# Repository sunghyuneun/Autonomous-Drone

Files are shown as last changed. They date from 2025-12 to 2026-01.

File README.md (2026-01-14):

# Overview
Similar to Turtlebot 3

- Features
    - Raspberry Pi 5
    - Arduino
    - DC Motors
    - Odometry
        - Encoders
        - IMU
        - LiDAR
    - SLAM (w/ LiDAR)
    - Obstacle Avoidance with PPO

# Progress

Drone Moving
https://www.youtube.com/watch?v=rg7pI7mpyLs

## LiDAR
Visualized LiDAR information from Raspberry Pi onto Desktop using RViz2.

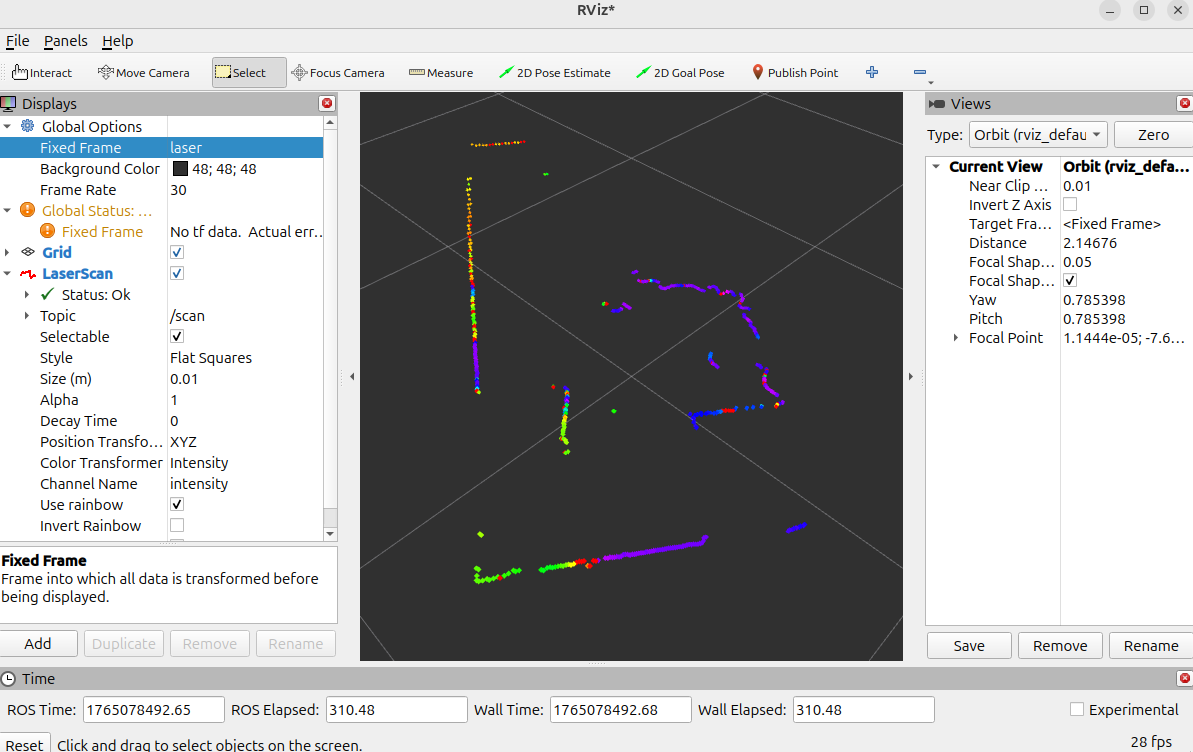
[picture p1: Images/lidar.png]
LiDar


After I moved, I could not set up proper port forwarding at my dorm between my Raspberry Pi and my VM, so I switched to Foxglove.

Here is an example Map with my robot and LiDAR visualized on it.
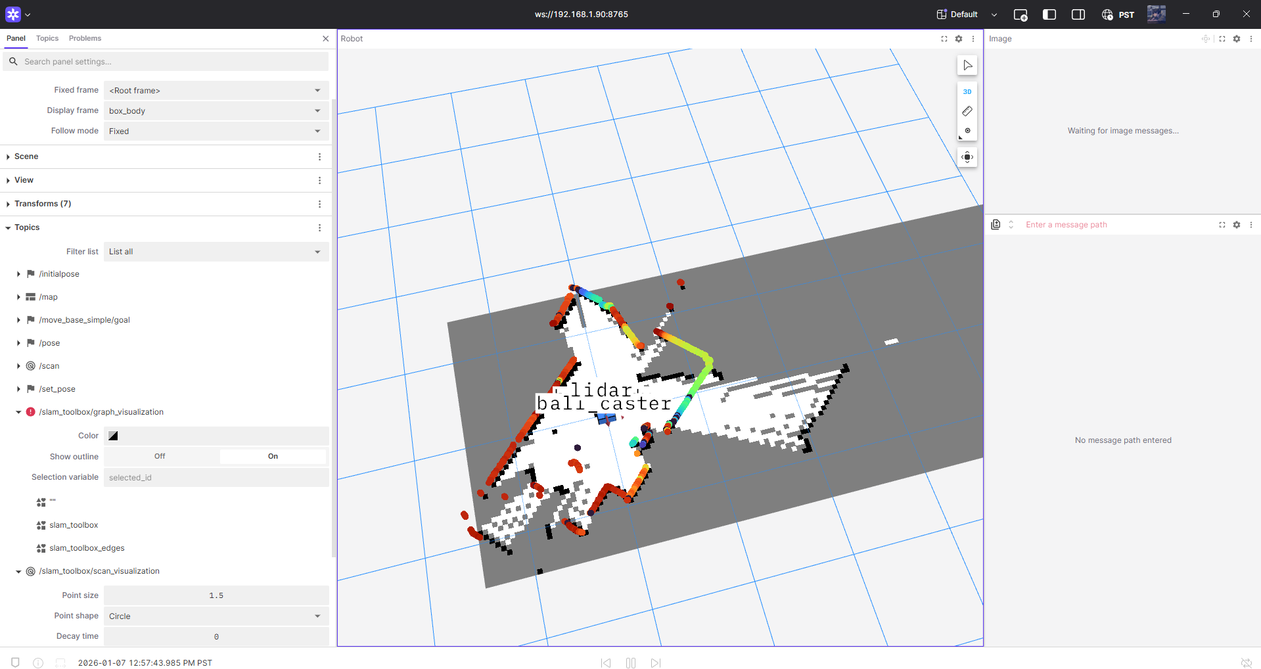
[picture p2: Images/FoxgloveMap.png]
Foxglove Map


## Assembly
Finished the CAD assembly, and built it in real life. 

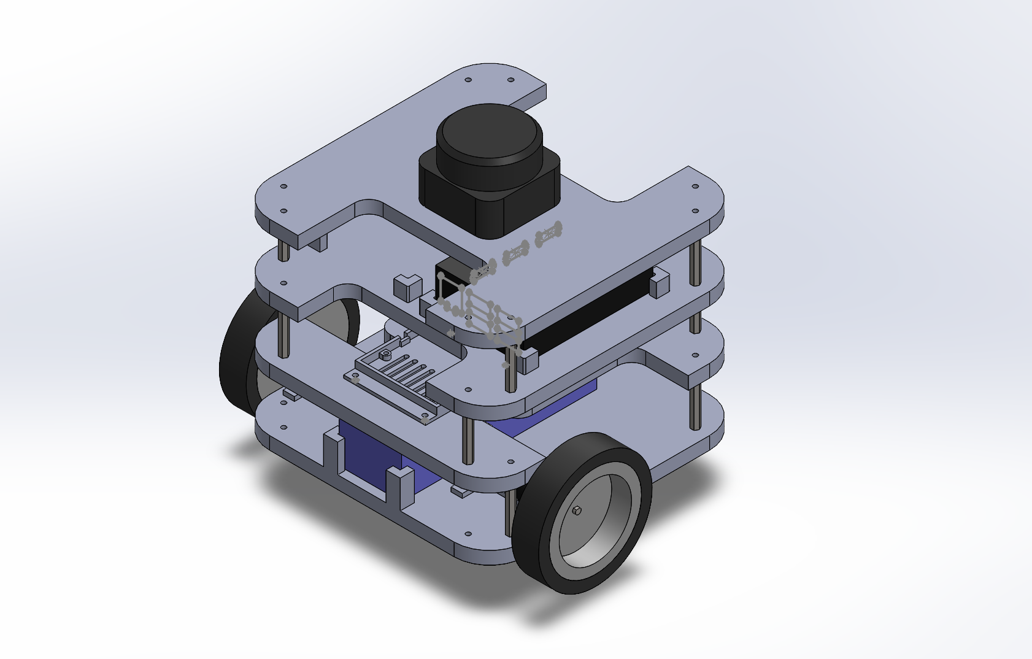
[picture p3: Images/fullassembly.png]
Full Assembly


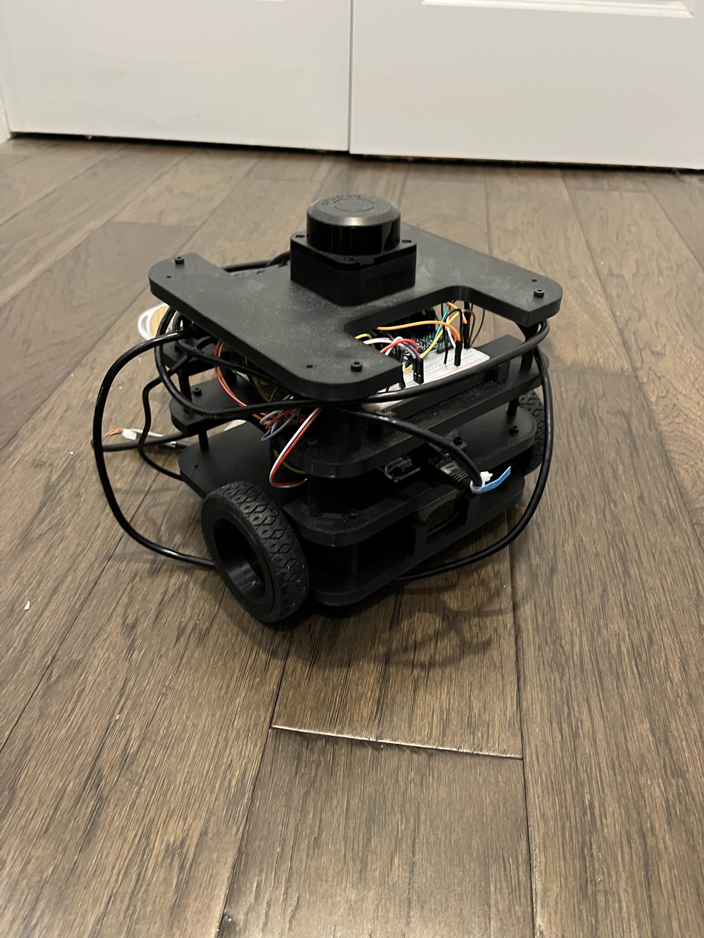
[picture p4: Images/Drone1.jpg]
Drone1


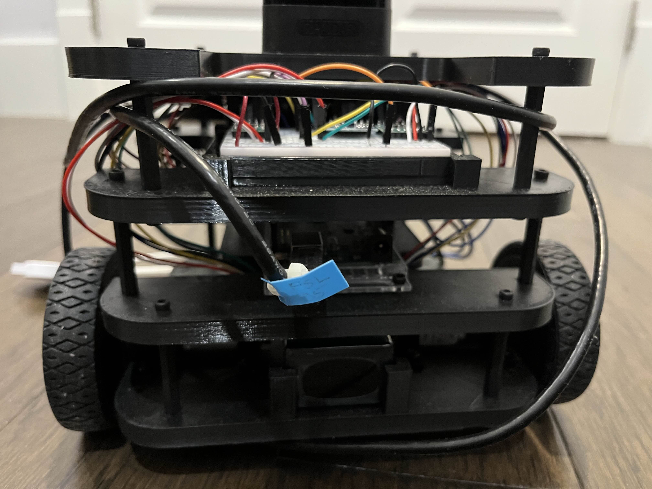
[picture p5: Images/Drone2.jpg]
Drone2


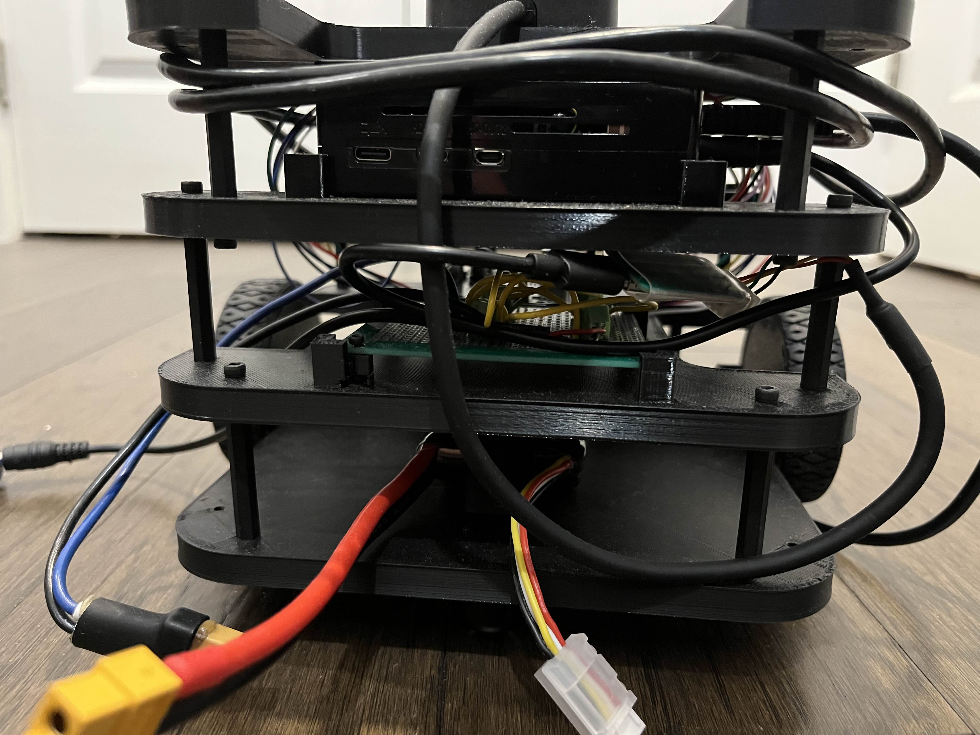
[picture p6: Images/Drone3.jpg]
Drone3


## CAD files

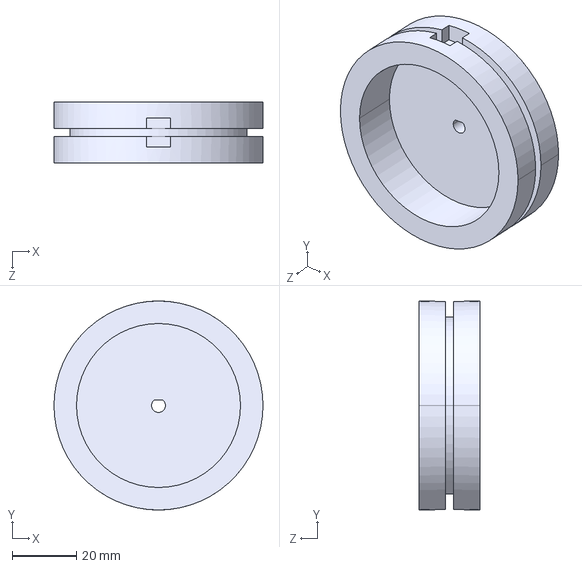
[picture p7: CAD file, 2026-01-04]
CAD/individual parts/wheel_rim.STEP
65.0 x 65.0 x 19.0 mm

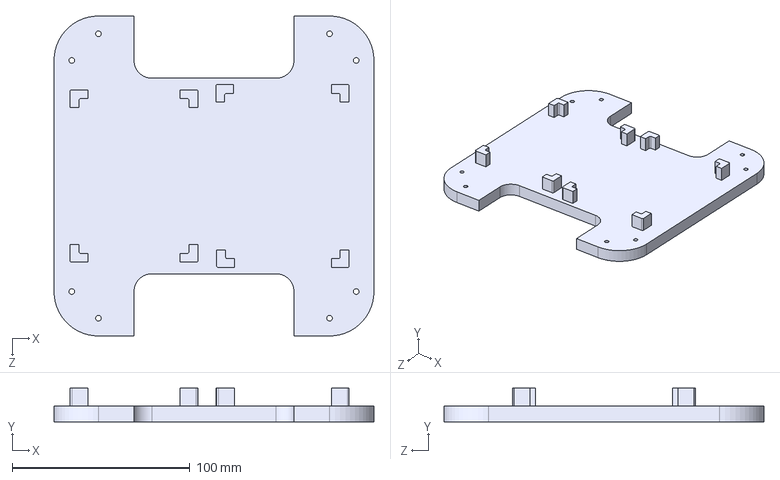
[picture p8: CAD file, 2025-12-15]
CAD/plates/plate3.STEP
180.0 x 19.0 x 180.0 mm

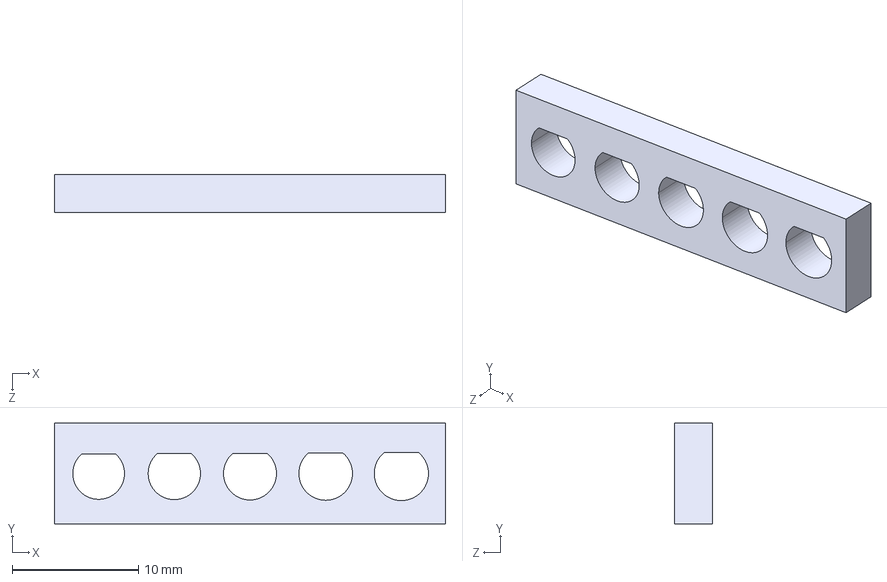
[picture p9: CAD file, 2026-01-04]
CAD/testprintagain.STEP
31.0 x 8.00 x 3.00 mm

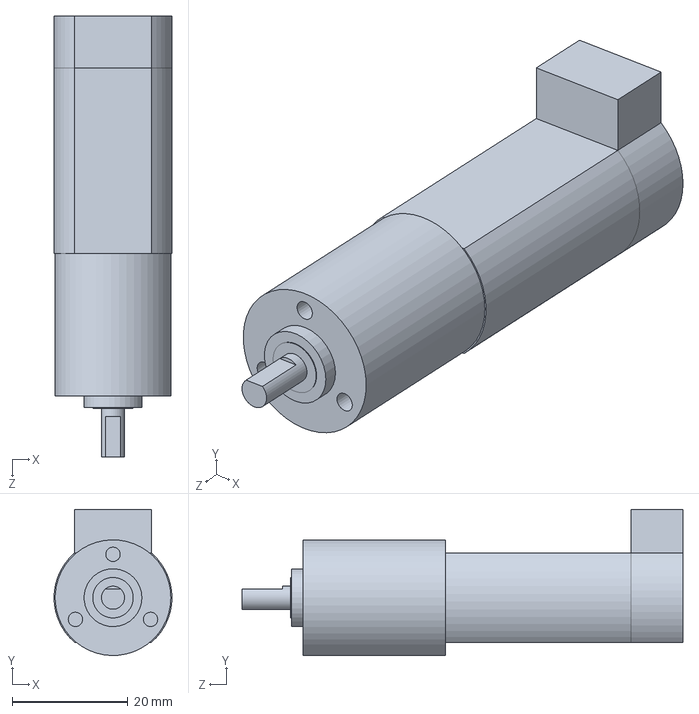
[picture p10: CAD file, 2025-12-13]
CAD/individual parts/motor.SLDPRT
20.4 x 25.2 x 76.2 mm

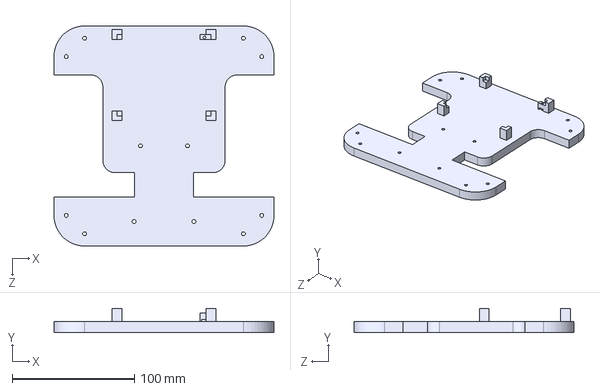
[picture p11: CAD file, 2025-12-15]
CAD/plates/plate2.STEP
180.0 x 20.0 x 180.0 mm

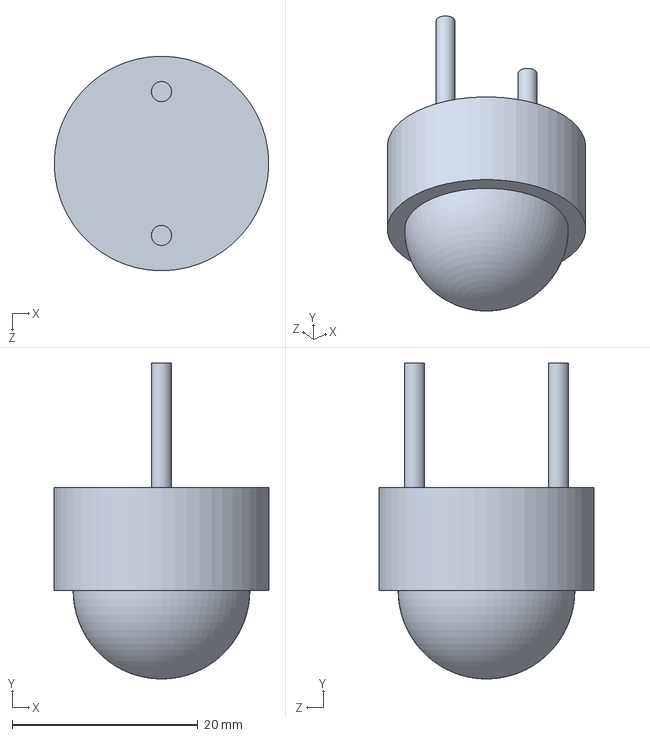
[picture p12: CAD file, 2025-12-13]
CAD/individual parts/ball_caster.SLDPRT
23.1 x 34.0 x 23.1 mm

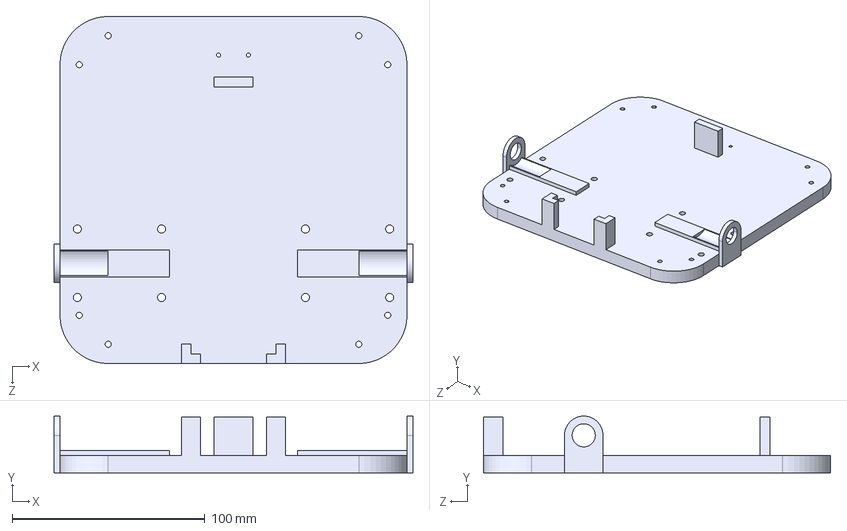
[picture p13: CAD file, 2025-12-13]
CAD/plates/plate1.STEP
186.0 x 29.5 x 180.0 mm

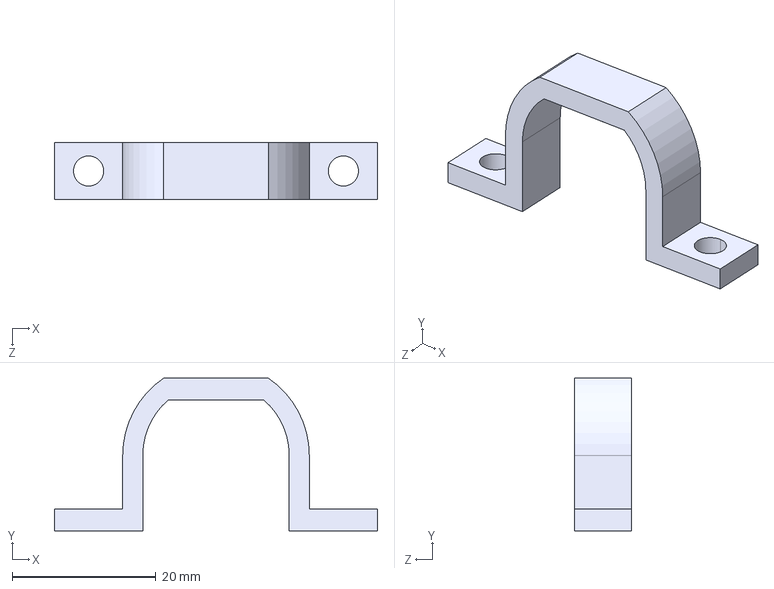
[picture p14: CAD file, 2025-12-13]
CAD/individual parts/clamp2.STEP
45.0 x 21.2 x 8.00 mm

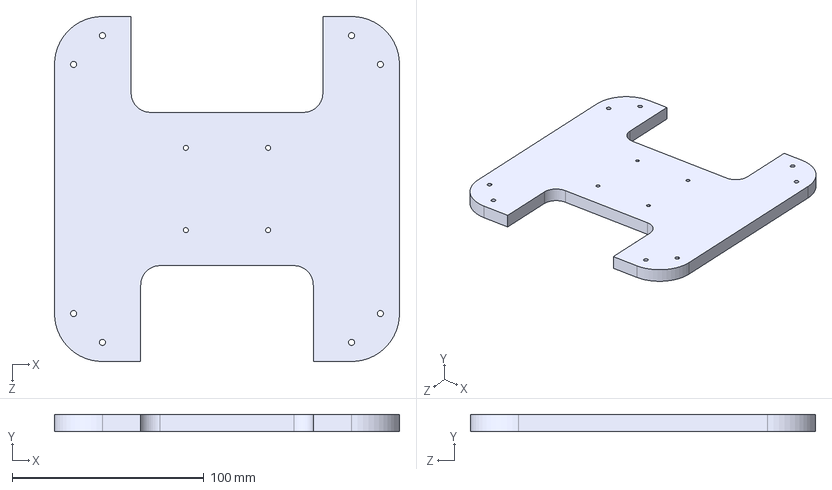
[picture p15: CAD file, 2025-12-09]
CAD/plates/plate4.STEP
180.0 x 9.00 x 180.0 mm

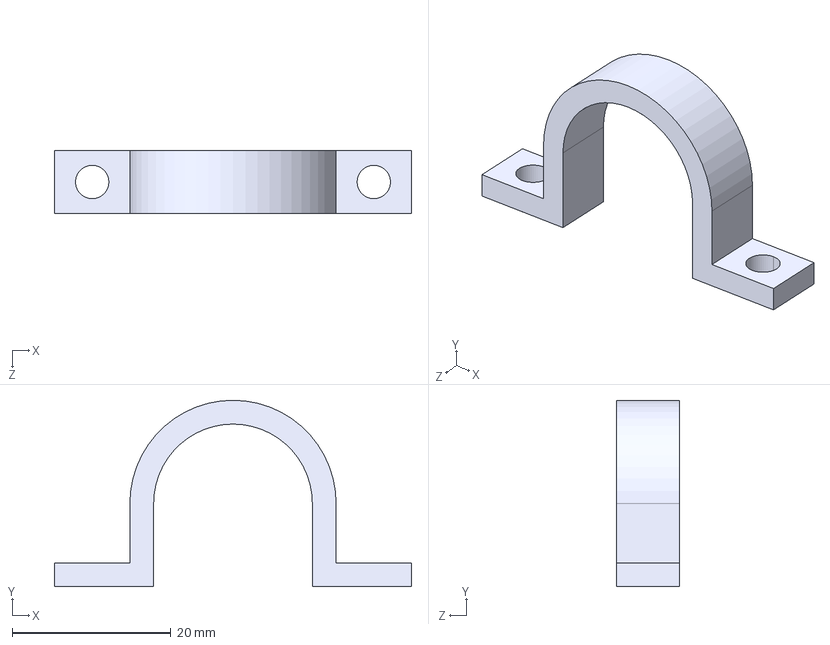
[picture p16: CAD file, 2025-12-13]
CAD/individual parts/clamp1.STEP
45.0 x 23.5 x 8.00 mm

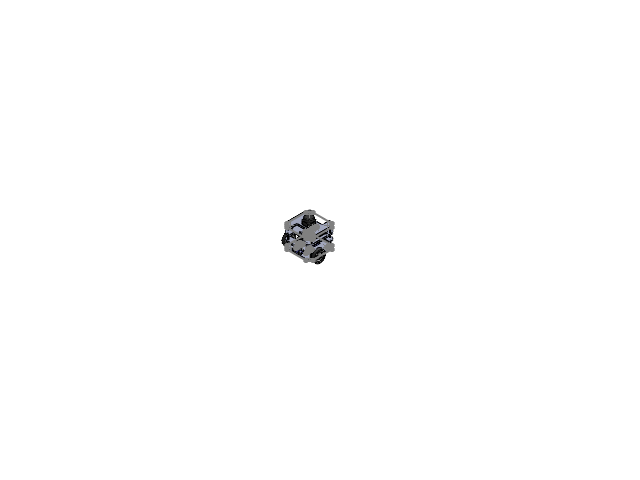
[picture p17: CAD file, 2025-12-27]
CAD/full_assembly.SLDASM
plate1
lipo
motor x 2
ball_caster
wheel_rim x 2
wheel_tire x 2
hex_standoff x 11
clamp1 x 2
clamp2 x 2
plate2
arduino_baseplate
plate3
raspberry_pi
plate4
lidar

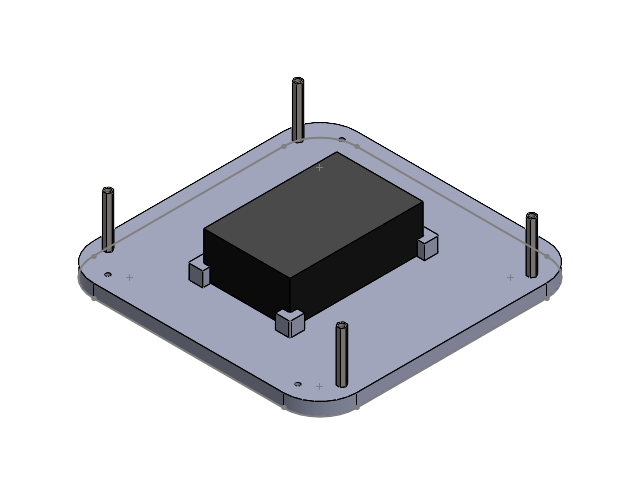
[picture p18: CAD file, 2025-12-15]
CAD/assembly3.SLDASM
plate3
raspberry_pi
hex_standoff x 4

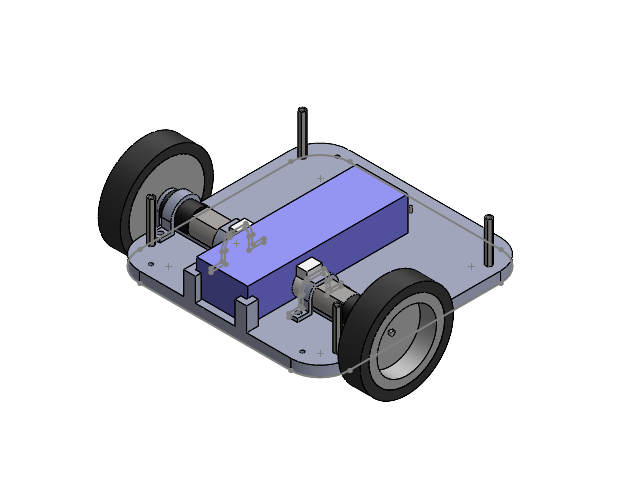
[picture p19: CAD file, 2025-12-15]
CAD/assembly1.SLDASM
plate1
lipo
motor x 2
ball_caster
wheel_rim x 2
wheel_tire x 2
hex_standoff x 4
clamp1 x 2
clamp2 x 2

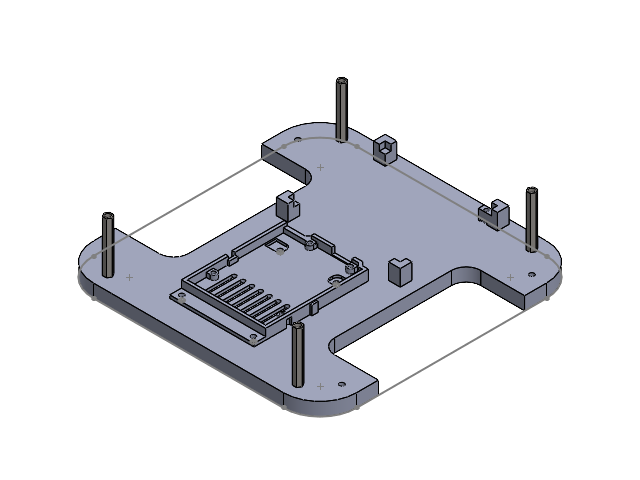
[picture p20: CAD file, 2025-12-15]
CAD/assembly2.SLDASM
plate2
arduino_baseplate
hex_standoff x 4

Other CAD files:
CAD/assembly4.SLDASM
CAD/full_assembly_stepper.SLDASM
CAD/assembly1_stepper.SLDASM
CAD/assembly2_stepper.SLDASM
CAD/individual parts/Arduino UNO Rev3_base original.stp
CAD/individual parts/GearMotor.SLDPRT
CAD/individual parts/Nema17.SLDPRT
CAD/individual parts/RPLidar C1.stp
CAD/individual parts/clamp1.SLDPRT
CAD/individual parts/clamp2.SLDPRT
CAD/individual parts/hex_standoff.SLDPRT
CAD/individual parts/lidar.SLDPRT
CAD/individual parts/lipo.SLDPRT
CAD/individual parts/raspberry_pi.SLDPRT
CAD/individual parts/wheel_rim.SLDPRT
CAD/individual parts/wheel_tire.SLDPRT
CAD/pcbtestprint.SLDPRT
CAD/pcbtestprint.STEP
CAD/plates/plate1.SLDPRT
CAD/plates/plate1_stepper.SLDPRT
CAD/plates/plate1_stepper.STEP
CAD/plates/plate2.SLDPRT
CAD/plates/plate2_stepper.SLDPRT
CAD/plates/plate2_stepper.STEP
CAD/plates/plate3.SLDPRT
CAD/plates/plate4.SLDPRT
CAD/testprint.SLDPRT
CAD/testprint.STEP
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

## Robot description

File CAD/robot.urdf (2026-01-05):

<robot name="autonomous_drone">
  <link name="box_body"> 
    <visual>
      <origin xyz="0 0 .0705" rpy="0 0 0" />
      <geometry>
        <box size=".18 .18 .141" />
      </geometry>
      <material name="Blue">
        <color rgba=".2588 .5294 .9608 .7"/>
      </material>
    </visual>
    
    <collision>
      <origin xyz="0 0 .0705" rpy="0 0 0"/>
      <geometry>
        <box size=".18 .18 .141" />
      </geometry>
    </collision>
  </link>

  <link name="wheel_right">
    <visual>
      <origin xyz="0 0 0" rpy="0 1.5708 0"/>
      <geometry>
        <cylinder radius = "0.04" length = ".019" />
      </geometry>
      <material name="Black">
        <color rgba="0 0 0 1"/>
      </material>
    </visual>
    
    <collision>
      <origin xyz="0 0 0" rpy="0 1.5708 0"/>
      <geometry>
        <cylinder radius = "0.04" length = ".019" />
      </geometry>
    </collision>
  </link>

  <link name="wheel_left" >
    <visual>
      <origin xyz="0 0 0" rpy="0 -1.5708 0"/>
      <geometry>
        <cylinder radius = "0.04" length = ".019" />
      </geometry>
      <material name="Black">
        <color rgba="0 0 0 1"/>
      </material>
    </visual>
    
    <collision>
      <origin xyz="0 0 0" rpy="0 -1.5708 0"/>
      <geometry>
        <cylinder radius = "0.04" length = ".019" />
      </geometry>
    </collision>
  </link>

  <link name="imu" >
    <visual>
      <origin xyz="0 0 0" rpy="0 0 0" />
      <geometry>
        <box size="0.021 .016 .005" />
      </geometry>
      <material name="Green">
        <color rgba="0 .3686 .0196 1"/>
      </material>
    </visual>
    
    <collision>
      <origin xyz="0 0 0" rpy="0 0 0" />
      <geometry>
        <box size="0.021 .016 .005" />
      </geometry>
    </collision>
  </link>

  <link name="lidar" >
    <visual>
      <origin xyz="0 0 0" rpy="0 0 0" />
      <geometry>
        <box size="0.0556 .0556 .0413" />
      </geometry>
      <material name="Black">
        <color rgba="0 0 0 1"/>
      </material>
    </visual>
    
    <collision>
      <origin xyz="0 0 0" rpy="0 0 0" />
      <geometry>
        <box size="0.0556 .0556 .0413" />
      </geometry>
    </collision>
  </link>

  <link name="ball_caster" >
    <visual>
      <origin xyz="0 0 0" rpy="0 0 0" />
      <geometry>
        <sphere radius =".009525" />
      </geometry>
      <material name="Blue">
        <color rgba=".2588 .5294 .9608 1"/>
      </material>
    </visual>
    
    <collision>
      <origin xyz="0 0 0" rpy="0 0 0" />
      <geometry>
        <sphere radius =".009525" />
      </geometry>
    </collision>
  </link>

  <joint name="right_wheel_joint" type="continuous">
    <origin xyz = "0.103 0.038 0.0195"/>
    <axis xyz="1 0 0" />
    <parent link="box_body"/>
    <child link="wheel_right"/>
  </joint>

  <joint name="left_wheel_joint" type="continuous">
    <origin xyz="-0.103 0.038 0.0195"/>
    <axis xyz="1 0 0" />
    <parent link="box_body"/>
    <child link="wheel_left"/>
  </joint>

  <joint name="imu_joint" type="fixed">
    <origin xyz="-0.0174 0.05225 0.114"/>
    <parent link="box_body"/>
    <child link="imu"/>
  </joint>

  <joint name="lidar_joint" type="fixed">
    <origin xyz="0 0 .16165" rpy="0 0 -1.5708"/>
    <parent link="box_body"/>
    <child link="lidar"/>
  </joint>

  <joint name="ball_joint" type="fixed">
    <origin xyz="0 -.07 -.01113"/>
    <parent link="box_body"/>
    <child link="ball_caster"/>
  </joint>
</robot>

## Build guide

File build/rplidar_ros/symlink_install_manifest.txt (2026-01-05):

/home/hyun/Autonomous-Drone/install/rplidar_ros/share/rplidar_ros/launch/rplidar_a1_launch.py
/home/hyun/Autonomous-Drone/install/rplidar_ros/share/rplidar_ros/launch/rplidar_a2m12_launch.py
/home/hyun/Autonomous-Drone/install/rplidar_ros/share/rplidar_ros/launch/rplidar_a2m7_launch.py
/home/hyun/Autonomous-Drone/install/rplidar_ros/share/rplidar_ros/launch/rplidar_a2m8_launch.py
/home/hyun/Autonomous-Drone/install/rplidar_ros/share/rplidar_ros/launch/rplidar_a3_launch.py
/home/hyun/Autonomous-Drone/install/rplidar_ros/share/rplidar_ros/launch/rplidar_c1_launch.py
/home/hyun/Autonomous-Drone/install/rplidar_ros/share/rplidar_ros/launch/rplidar_s1_launch.py
/home/hyun/Autonomous-Drone/install/rplidar_ros/share/rplidar_ros/launch/rplidar_s1_tcp_launch.py
/home/hyun/Autonomous-Drone/install/rplidar_ros/share/rplidar_ros/launch/rplidar_s2_launch.py
/home/hyun/Autonomous-Drone/install/rplidar_ros/share/rplidar_ros/launch/rplidar_s2e_launch.py
/home/hyun/Autonomous-Drone/install/rplidar_ros/share/rplidar_ros/launch/rplidar_s3_launch.py
/home/hyun/Autonomous-Drone/install/rplidar_ros/share/rplidar_ros/launch/rplidar_t1_launch.py
/home/hyun/Autonomous-Drone/install/rplidar_ros/share/rplidar_ros/launch/view_rplidar_a1_launch.py
/home/hyun/Autonomous-Drone/install/rplidar_ros/share/rplidar_ros/launch/view_rplidar_a2m12_launch.py
/home/hyun/Autonomous-Drone/install/rplidar_ros/share/rplidar_ros/launch/view_rplidar_a2m7_launch.py
/home/hyun/Autonomous-Drone/install/rplidar_ros/share/rplidar_ros/launch/view_rplidar_a2m8_launch.py
/home/hyun/Autonomous-Drone/install/rplidar_ros/share/rplidar_ros/launch/view_rplidar_a3_launch.py
/home/hyun/Autonomous-Drone/install/rplidar_ros/share/rplidar_ros/launch/view_rplidar_c1_launch.py
/home/hyun/Autonomous-Drone/install/rplidar_ros/share/rplidar_ros/launch/view_rplidar_s1_launch.py
/home/hyun/Autonomous-Drone/install/rplidar_ros/share/rplidar_ros/launch/view_rplidar_s1_tcp_launch.py
/home/hyun/Autonomous-Drone/install/rplidar_ros/share/rplidar_ros/launch/view_rplidar_s2_launch.py
/home/hyun/Autonomous-Drone/install/rplidar_ros/share/rplidar_ros/launch/view_rplidar_s2e_launch.py
/home/hyun/Autonomous-Drone/install/rplidar_ros/share/rplidar_ros/launch/view_rplidar_s3_launch.py
/home/hyun/Autonomous-Drone/install/rplidar_ros/share/rplidar_ros/launch/view_rplidar_t1_launch.py
/home/hyun/Autonomous-Drone/install/rplidar_ros/share/rplidar_ros/rviz/rplidar_ros.rviz
/home/hyun/Autonomous-Drone/install/rplidar_ros/lib/rplidar_ros/rplidar_node
/home/hyun/Autonomous-Drone/install/rplidar_ros/lib/rplidar_ros/rplidar_composition
/home/hyun/Autonomous-Drone/install/rplidar_ros/lib/rplidar_ros/rplidar_client
/home/hyun/Autonomous-Drone/install/rplidar_ros/share/ament_index/resource_index/package_run_dependencies/rplidar_ros
/home/hyun/Autonomous-Drone/install/rplidar_ros/share/ament_index/resource_index/parent_prefix_path/rplidar_ros
/home/hyun/Autonomous-Drone/install/rplidar_ros/share/rplidar_ros/environment/ament_prefix_path.sh
/home/hyun/Autonomous-Drone/install/rplidar_ros/share/rplidar_ros/environment/ament_prefix_path.dsv
/home/hyun/Autonomous-Drone/install/rplidar_ros/share/rplidar_ros/environment/path.sh
/home/hyun/Autonomous-Drone/install/rplidar_ros/share/rplidar_ros/environment/path.dsv
/home/hyun/Autonomous-Drone/install/rplidar_ros/share/rplidar_ros/local_setup.bash
/home/hyun/Autonomous-Drone/install/rplidar_ros/share/rplidar_ros/local_setup.sh
/home/hyun/Autonomous-Drone/install/rplidar_ros/share/rplidar_ros/local_setup.zsh
/home/hyun/Autonomous-Drone/install/rplidar_ros/share/rplidar_ros/local_setup.dsv
/home/hyun/Autonomous-Drone/install/rplidar_ros/share/rplidar_ros/package.dsv
/home/hyun/Autonomous-Drone/install/rplidar_ros/share/ament_index/resource_index/packages/rplidar_ros
/home/hyun/Autonomous-Drone/install/rplidar_ros/share/rplidar_ros/cmake/ament_cmake_export_dependencies-extras.cmake
/home/hyun/Autonomous-Drone/install/rplidar_ros/share/rplidar_ros/cmake/ament_cmake_export_include_directories-extras.cmake
/home/hyun/Autonomous-Drone/install/rplidar_ros/share/rplidar_ros/cmake/rplidar_rosConfig.cmake
/home/hyun/Autonomous-Drone/install/rplidar_ros/share/rplidar_ros/cmake/rplidar_rosConfig-version.cmake
/home/hyun/Autonomous-Drone/install/rplidar_ros/share/rplidar_ros/package.xml

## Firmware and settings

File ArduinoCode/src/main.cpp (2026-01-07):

#define ENCODER_OPTIMIZE_INTERRUPTS

#include <Arduino.h>
#include <Wire.h>
#include <Adafruit_Sensor.h>
#include <Adafruit_MPU6050.h>
#include <Encoder.h>

/*
IMU SCL - SCL
IMU SDA - SDA

1 - Right Motor
2 - Left Motor

EN 1 - Pin 9
EN 2 - Pin 10
PH 1 - Pin 11
PH 2 - Pin 12

Hall Signal 1 A - Pin 2
Hall Signal 2 A - Pin 3
Hall Signal 1 B - Pin 4
Hall Signal 2 B - Pin 5
*/

const int HALL1A = 2;
const int HALL2A = 3;
const int HALL1B = 4;
const int HALL2B = 5;

const int EN1 = 9;
const int EN2 = 10;
const int PH1 = 11;
const int PH2 = 12;

const float PPR = 11.0;
const float GEAR_RATIO = 157.0;
const float WHEEL_RADIUS = 0.04;
const float TICKS_PER_REV = PPR * GEAR_RATIO;
const float METERS_PER_TICK = (WHEEL_RADIUS * 2 * PI) / TICKS_PER_REV;

unsigned int last_time = 0;
long last_pos1 = 0;
long last_pos2 = 0;
long current_pos1 = 0;
long current_pos2 = 0;

const int interval = 50;

float X_ACCEL_BIAS;
float Y_ACCEL_BIAS;
float Z_ACCEL_BIAS;
float X_GYRO_BIAS;
float Y_GYRO_BIAS;
float Z_GYRO_BIAS;

Adafruit_MPU6050 mpu;
Encoder encoder1(HALL1A,HALL1B);
Encoder encoder2(HALL2A,HALL2B);

float vel_1 = 0.0;
float vel_2 = 0.0;


//float kp = 150.0;
//float ki = 40.0;
//float kd = 1.0;
float kp = 250.0;
float ki = 100.0;
float kd = 0.0;
//Yeah these seem to work let's just go with a PI controller lol

float target_vel_1 = 0.0;
float target_vel_2 = 0.0;
float integral1 = 0.0;
float integral2 = 0.0;
float last_error_1 = 0.0;
float last_error_2 = 0.0;


void IMU_Calibration();
void print_IMU();
void drive_motor(float, float);

void setup() {
  pinMode(HALL1A, INPUT);
  pinMode(HALL2A, INPUT);
  pinMode(HALL1B, INPUT);
  pinMode(HALL2B, INPUT);

  pinMode(EN1, OUTPUT);
  pinMode(EN2, OUTPUT);
  pinMode(PH1, OUTPUT);
  pinMode(PH2, OUTPUT);

  Serial.begin(115200);
  while (!Serial){
    delay(10);
  }

  if (!mpu.begin()){
    Serial.println("Failed to find MPU6050!");
    while (1){
      delay(10);
    }
  }

  encoder1.write(0);
  encoder2.write(0);

  mpu.setAccelerometerRange(MPU6050_RANGE_16_G);
  mpu.setGyroRange(MPU6050_RANGE_250_DEG);
  mpu.setFilterBandwidth(MPU6050_BAND_21_HZ);
  Serial.println("");
  delay(100);
  IMU_Calibration();
}

void loop() {
  unsigned long current_time = millis();

  sensors_event_t a, g, temp;
  mpu.getEvent(&a, &g, &temp);

  if (Serial.available() > 0){
    char key = Serial.read();
    if (key == 'R'){
      target_vel_1 = -1 * Serial.parseFloat();
      Serial.print("R: ");
      Serial.println(target_vel_1);
    }
    else if (key == 'L'){
      target_vel_2 = Serial.parseFloat();
      Serial.print("L: ");
      Serial.println(target_vel_2);
    }
  }

  if ((current_time - last_time) >= interval){
    current_pos1 = encoder1.read();
    current_pos2 = encoder2.read();

    float time_delta = (current_time - last_time) / 1000.0;
    vel_1 = (current_pos1 - last_pos1) * METERS_PER_TICK / time_delta;
    vel_2 = (current_pos2 - last_pos2) * METERS_PER_TICK / time_delta;
    Serial.print("V:");
    Serial.print(-1 * vel_1);
    Serial.print(",");
    Serial.print(vel_2);
    Serial.print(",");

    last_pos1 = current_pos1;
    last_pos2 = current_pos2;
    last_time = current_time;

    Serial.print(a.acceleration.x - X_ACCEL_BIAS);
    Serial.print(",");
    Serial.print(a.acceleration.y - Y_ACCEL_BIAS);
    Serial.print(",");
    Serial.print(a.acceleration.z - Z_ACCEL_BIAS);
    Serial.print(",");

    Serial.print(g.gyro.x - X_GYRO_BIAS);
    Serial.print(",");
    Serial.print(g.gyro.y - Y_GYRO_BIAS);
    Serial.print(",");
    Serial.print(g.gyro.z - Z_GYRO_BIAS);
    Serial.print("\n");

    float error1 = target_vel_1 - vel_1;
    float error2 = target_vel_2 - vel_2;
    integral1 += error1 * time_delta;
    integral1 = constrain(integral1, -100, 100);
    integral2 += error2 * time_delta;
    integral2 = constrain(integral2, -100, 100);
    float derivative1 = (error1 - last_error_1) / time_delta;
    float derivative2 = (error2 - last_error_2) / time_delta;
    float output1 = (kp * error1) + (ki * integral1) + (kd * derivative1);
    float output2 = (kp * error2) + (ki * integral2) + (kd * derivative2);

    drive_motor(output1, output2);
    last_error_1 = error1;
    last_error_2 = error2;
  }
}

void IMU_Calibration(){

  const int CALIB_TIMESTEPS = 1000;
  double X_ACCEL_SUM = 0;
  double Y_ACCEL_SUM = 0;
  double Z_ACCEL_SUM = 0;
  double X_GYRO_SUM = 0;
  double Y_GYRO_SUM = 0;
  double Z_GYRO_SUM = 0;
  for (int i = 0; i < CALIB_TIMESTEPS; i++){
    sensors_event_t a, g, temp;
    mpu.getEvent(&a, &g, &temp);
    X_ACCEL_SUM += a.acceleration.x;
    Y_ACCEL_SUM += a.acceleration.y;
    Z_ACCEL_SUM += a.acceleration.z;

    X_GYRO_SUM += g.gyro.x;
    Y_GYRO_SUM += g.gyro.y;
    Z_GYRO_SUM += g.gyro.z;
  }

  X_ACCEL_BIAS = X_ACCEL_SUM / (float) CALIB_TIMESTEPS;
  Y_ACCEL_BIAS = Y_ACCEL_SUM / (float) CALIB_TIMESTEPS;
  Z_ACCEL_BIAS = Z_ACCEL_SUM / (float) CALIB_TIMESTEPS;
  X_GYRO_BIAS = X_GYRO_SUM / (float) CALIB_TIMESTEPS;
  Y_GYRO_BIAS = Y_GYRO_SUM / (float) CALIB_TIMESTEPS;
  Z_GYRO_BIAS = Z_GYRO_SUM / (float) CALIB_TIMESTEPS;
  /*
  Serial.print("IMU Calibrated.");

  Serial.print(X_ACCEL_BIAS);
  Serial.print(",");
  Serial.print(Y_ACCEL_BIAS);
  Serial.print(",");
  Serial.print(Z_ACCEL_BIAS);
  Serial.print(",");
  Serial.print(X_GYRO_BIAS);
  Serial.print(",");
  Serial.print(Y_GYRO_BIAS);
  Serial.print(",");
  Serial.print(Z_GYRO_BIAS);
  Serial.print("\n");
  */
}


void drive_motor(float power1, float power2){
  if (power1 >= 0) digitalWrite(PH1, HIGH);
  else digitalWrite(PH1, LOW);
  if (power2 >= 0) digitalWrite(PH2, HIGH);
  else digitalWrite(PH2, LOW);
  int pwmVal1;
  int pwmVal2;
  if (abs(target_vel_1) < 0.0001) pwmVal1 = 0;
  else pwmVal1 = constrain(abs(power1), 0, 255);
  if (abs(target_vel_2) < 0.0001) pwmVal2 = 0;
  else pwmVal2 = constrain(abs(power2), 0, 255);
  //Max is like 1.64 lol
  analogWrite(EN1, pwmVal1);
  analogWrite(EN2, pwmVal2);
}

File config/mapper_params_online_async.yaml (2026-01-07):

slam_toolbox:
  ros__parameters:

    # Plugin params
    solver_plugin: solver_plugins::CeresSolver
    ceres_linear_solver: SPARSE_NORMAL_CHOLESKY
    ceres_preconditioner: SCHUR_JACOBI
    ceres_trust_strategy: LEVENBERG_MARQUARDT
    ceres_dogleg_type: TRADITIONAL_DOGLEG
    ceres_loss_function: None

    # ROS Parameters
    odom_frame: odom
    map_frame: map
    base_frame: box_body
    scan_topic: /scan
    use_map_saver: true
    mode: mapping #localization

    # if you'd like to immediately start continuing a map at a given pose
    # or at the dock, but they are mutually exclusive, if pose is given
    # will use pose
    #map_file_name: test_steve
    # map_start_pose: [0.0, 0.0, 0.0]
    #map_start_at_dock: true

    debug_logging: false
    throttle_scans: 1
    transform_publish_period: 0.02 #if 0 never publishes odometry
    map_update_interval: 5.0
    resolution: 0.05
    max_laser_range: 20.0 #for rastering images
    minimum_time_interval: 0.5
    transform_timeout: 0.2
    tf_buffer_duration: 30.0
    stack_size_to_use: 40000000 #// program needs a larger stack size to serialize large maps
    enable_interactive_mode: true

    # General Parameters
    use_scan_matching: true
    use_scan_barycenter: true
    minimum_travel_distance: 0.5
    minimum_travel_heading: 0.5
    scan_buffer_size: 10
    scan_buffer_maximum_scan_distance: 10.0
    link_match_minimum_response_fine: 0.1  
    link_scan_maximum_distance: 1.5
    loop_search_maximum_distance: 3.0
    do_loop_closing: true 
    loop_match_minimum_chain_size: 10           
    loop_match_maximum_variance_coarse: 3.0  
    loop_match_minimum_response_coarse: 0.35    
    loop_match_minimum_response_fine: 0.45

    # Correlation Parameters - Correlation Parameters
    correlation_search_space_dimension: 0.5
    correlation_search_space_resolution: 0.01
    correlation_search_space_smear_deviation: 0.1 

    # Correlation Parameters - Loop Closure Parameters
    loop_search_space_dimension: 8.0
    loop_search_space_resolution: 0.05
    loop_search_space_smear_deviation: 0.03

    # Scan Matcher Parameters
    distance_variance_penalty: 0.5      
    angle_variance_penalty: 1.0    

    fine_search_angle_offset: 0.00349     
    coarse_search_angle_offset: 0.349   
    coarse_angle_resolution: 0.0349        
    minimum_angle_penalty: 0.9
    minimum_distance_penalty: 0.5
    use_response_expansion: true
    min_pass_through: 2
    occupancy_threshold: 0.1

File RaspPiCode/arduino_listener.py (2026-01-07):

import serial
import rclpy
from rclpy.node import Node
from nav_msgs.msg import Odometry
from sensor_msgs.msg import Imu
from geometry_msgs.msg import Quaternion, TransformStamped
import math
import tf_transformations

SERIAL_PORT = '/dev/ttyACM0'
BAUD_RATE = 115200
WHEEL_SEPARATION = .206 #206 mm

class ArduinoPublisher(Node):
    def __init__(self):
        super().__init__('arduino_publisher')

        self.imu_publisher = self.create_publisher(Imu, 'imu/raw_data', 10)
        self.get_logger().info("Created IMU Data Publisher")

        self.odom_publisher = self.create_publisher(Odometry, 'odom', 10)
        self.get_logger().info("Created Odometry Publisher")

        try:
            self.ser = serial.Serial(SERIAL_PORT, BAUD_RATE, timeout = .1)
            self.get_logger().info("Connected to Arduino Serial")
        except Exception as e:
            self.get_logger().error(f"Could not open serial port: {e}")

        self.x = 0.0
        self.y = 0.0
        self.th = 0.0
        self.last_time = self.get_clock().now()

        self.create_timer(0.02,self.publish_info)


    def publish_info(self):
        #write_data = "L0.1R0.1" + '\n'
        #self.ser.write(write_data.encode("utf-8"))
        if hasattr(self,'ser') and self.ser.in_waiting > 0:
            try:
                line = self.ser.readline().decode('utf-8', errors='ignore').strip()
                
                if line.startswith("V:"):
                    try:
                        data_parts = [float(val) for val in line[2:].split(',')]
                        
                        if len(data_parts) != 8:
                            self.get_logger().warn(f"Data packet length mismatch, length = {data_parts}")
                            return

                        
                        current_time = self.get_clock().now()

                        v_right, v_left = data_parts[0],data_parts[1]

                        #IMU stuff. 
                        imu_msg = Imu()
                        imu_msg.header.stamp = current_time.to_msg()
                        imu_msg.header.frame_id = "imu"

                        imu_msg.linear_acceleration.x = data_parts[2]
                        imu_msg.linear_acceleration.y = data_parts[3]
                        imu_msg.linear_acceleration.z = data_parts[4]
                        
                        imu_msg.angular_velocity.x = data_parts[5]
                        imu_msg.angular_velocity.x = data_parts[6]
                        imu_msg.angular_velocity.x = data_parts[7]

                        self.imu_publisher.publish(imu_msg)

                        #Odom stuff
                        dt = (current_time - self.last_time).nanoseconds / 1e9

                        v_linear = (v_right + v_left) / 2.0
                        v_angular = (v_right - v_left) / WHEEL_SEPARATION

                        self.x += (v_linear * math.cos(self.th)) * dt
                        self.y += (v_linear * math.sin(self.th)) * dt
                        self.th += v_angular * dt

                        q = tf_transformations.quaternion_from_euler(0, 0, self.th)
                        odom_msg = Odometry()
                        odom_msg.header.stamp = current_time.to_msg()
                        odom_msg.header.frame_id = "odom"
                        odom_msg.child_frame_id = 'box_body'

                        odom_msg.pose.pose.position.x = self.x
                        odom_msg.pose.pose.position.y = self.y
                        odom_msg.pose.pose.orientation = Quaternion(x=q[0], y=q[1], z=q[2], w=q[3])

                        odom_msg.twist.twist.linear.x = v_linear
                        odom_msg.twist.twist.angular.z = v_angular

                        # 5. Publish
                        self.odom_publisher.publish(odom_msg)
                        self.last_time = current_time

                    except ValueError:
                        self.get_logger().error(f"Failed to parse data: {line[2:]}")

            except Exception as e:
                self.get_logger().error(f"Error reading serial data: {e}")

def main(args = None):
    rclpy.init(args=args)

    arduino_publisher = ArduinoPublisher()

    try:
        rclpy.spin(arduino_publisher)
    except KeyboardInterrupt:
        pass
    finally:
        arduino_publisher.destroy_node()
        rclpy.shutdown()


if __name__ == '__main__':
    main()

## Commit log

2025-12-02 Fixed ROS2 publisher node
    [desktop.py]
2025-12-02 Fixed Firmware on Arduino
    [main.cpp]
2025-12-02 fixed data type issues
    [rasppi.py]
2025-12-03 Initial CAD
    [ball_caster.SLDPRT, full_assembly.SLDASM, hex_standoff.SLDPRT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]
2025-12-05 edited CAD further
    [ball_caster.SLDPRT, full_assembly.SLDASM, lidar.SLDPRT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]
2025-12-06 moved into a folder
    [GearMotor.SLDPRT, Nema17.SLDPRT, testprint.SLDPRT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]
2025-12-07 started new assembly
    [stepper_assembly.SLDASM, stepper_plate.SLDPRT]
2025-12-07 Did a bunch of work
    [Arduino UNO Rev3_base original.stp, Arduino Uno.SLDPRT, GearMotor.SLDPRT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]
2025-12-08 printed stuff
    [assembly1_stepper.SLDASM, ball_caster.SLDPRT, full_assembly_stepper.SLDASM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]
2025-12-09 Added tolerances and made big update to CAD
    [assembly1.SLDASM, assembly1_stepper.SLDASM, assembly2.SLDASM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]
2025-12-09 send to print the file
    [assembly1.SLDASM, plate1.SLDPRT, plate4.SLDPRT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]
2025-12-09 Rounded out some edges
    [assembly2.SLDASM, assembly3.SLDASM, assembly4.SLDASM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]
2025-12-09 created a working test print
    [pcbtestprint.SLDPRT, pcbtestprint.STEP]
2025-12-09 Created Stepper Test
    [assembly1.SLDASM, clamp1.SLDPRT, motor.SLDPRT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]
2025-12-11 Added clamps, PCB to CAD
    [assembly1.SLDASM, assembly2.SLDASM, assembly3.SLDASM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]
2025-12-13 Additional tolerances
    [clamp1.STEP, clamp2.SLDPRT, clamp2.STEP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]
2025-12-13 fixed CAD further
    [assembly1.SLDASM, assembly2.SLDASM, assembly4.SLDASM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]
2025-12-15 CAD Editing
    [assembly1.SLDASM, assembly2.SLDASM, assembly3.SLDASM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]
2025-12-25 Created working Arduino code to give IMU and Encoder Information over Serial
2025-12-26 Added Arduino Listener
2025-12-27 need to make URDF DAMN IT
    [full_assembly.SLDASM, robot.urdf]
2025-12-27 COMMIT PLEASE
    [robot.urdf]
2025-12-28 Push push push push
    [robot.urdf]
2025-12-28 Created PID control for the bot
2026-01-04 pushed actual tolerances
    [testprintagain.SLDPRT, testprintagain.STEP, wheel_rim.SLDPRT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]
2026-01-04 Fixed URDF completely.
    [robot.urdf]
2026-01-05 WORKING ROBOT STATE PUBLISHER + FOXGLOVE + LIDAR RAHHHHHHHHHHHHHHHHHH
    [robot.urdf]
2026-01-07 Edited PID controller values
2026-01-07 A little extra change to fix 0 velocity
    [main.cpp]
